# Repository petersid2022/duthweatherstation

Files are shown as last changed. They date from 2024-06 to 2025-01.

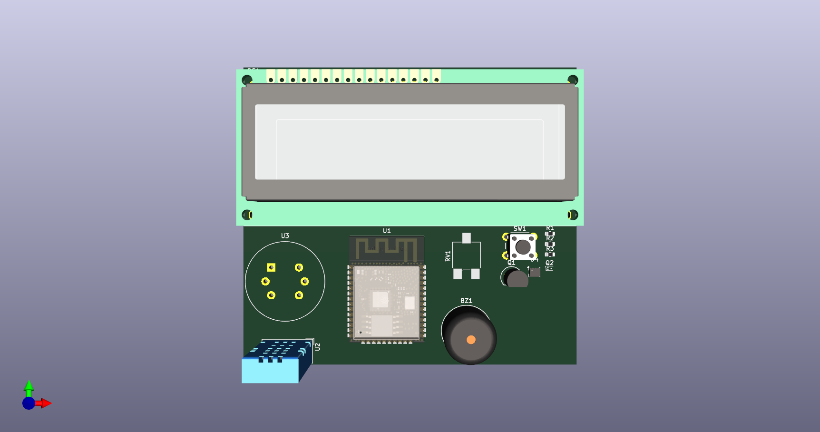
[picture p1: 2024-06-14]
esp32/1.png

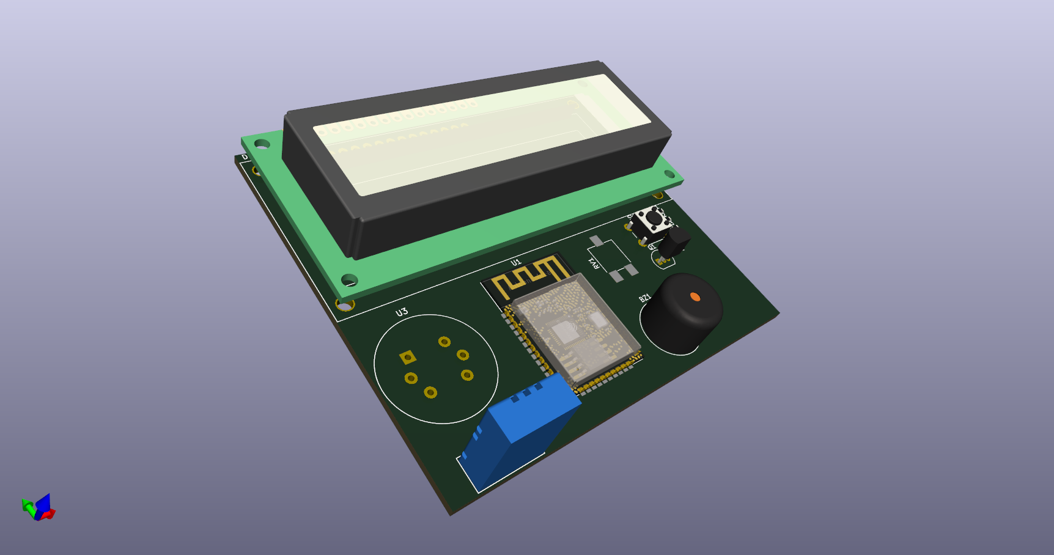
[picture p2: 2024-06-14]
esp32/2.png

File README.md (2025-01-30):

# duthweatherstation

This repo contains a proposed implementation of an Integrated Automatic Weather Station, centered around the FireBeetle 2 ESP32-E microcontroller, that's based on the ESP-WROOM-32E, chosen for its ultra-low power consumption, on-board charging circuit and compatibility with a wide range of sensors. The sensor array includes a DHT11 for humidity, a BMP180 for temperature and barometric pressure, and an MQ135 for air quality monitoring.

Included in this repo:
* The ESP32 firmware
* The Go microservice that handles the data stream from the ESP32 and various SQL transactions with the MySQL database
* Our Go/TEMPL frontend app
* The final board schematic, designed using KiCad
* Various 3D renderings of the PCB generated using KiCad
* The paper that describes in detail our implementation

~~You can view the live production app on: https://duthweatherstation.azurewebsites.net/~~





## License
This project is licensed under the MIT License.

(The MIT License)
Copyright (c) 2024 Peter Sideris petersid2022@gmail.com
Permission is hereby granted, free of charge, to any person obtaining a copy of this software and associated documentation files (the 'Software'), to deal in the Software without restriction, including without limitation the rights to use, copy, modify, merge, publish, distribute, sublicense, and/or sell copies of the Software, and to permit persons to whom the Software is furnished to do so, subject to the following conditions:
The above copyright notice and this permission notice shall be included in all copies or substantial portions of the Software.
THE SOFTWARE IS PROVIDED 'AS IS', WITHOUT WARRANTY OF ANY KIND, EXPRESS OR IMPLIED, INCLUDING BUT NOT LIMITED TO THE WARRANTIES OF MERCHANTABILITY, FITNESS FOR A PARTICULAR PURPOSE AND NONINFRINGEMENT. IN NO EVENT SHALL THE AUTHORS OR COPYRIGHT HOLDERS BE LIABLE FOR ANY CLAIM, DAMAGES OR OTHER LIABILITY, WHETHER IN AN ACTION OF CONTRACT, TORT OR OTHERWISE, ARISING FROM, OUT OF OR IN CONNECTION WITH THE SOFTWARE OR THE USE OR OTHER DEALINGS IN THE SOFTWARE.

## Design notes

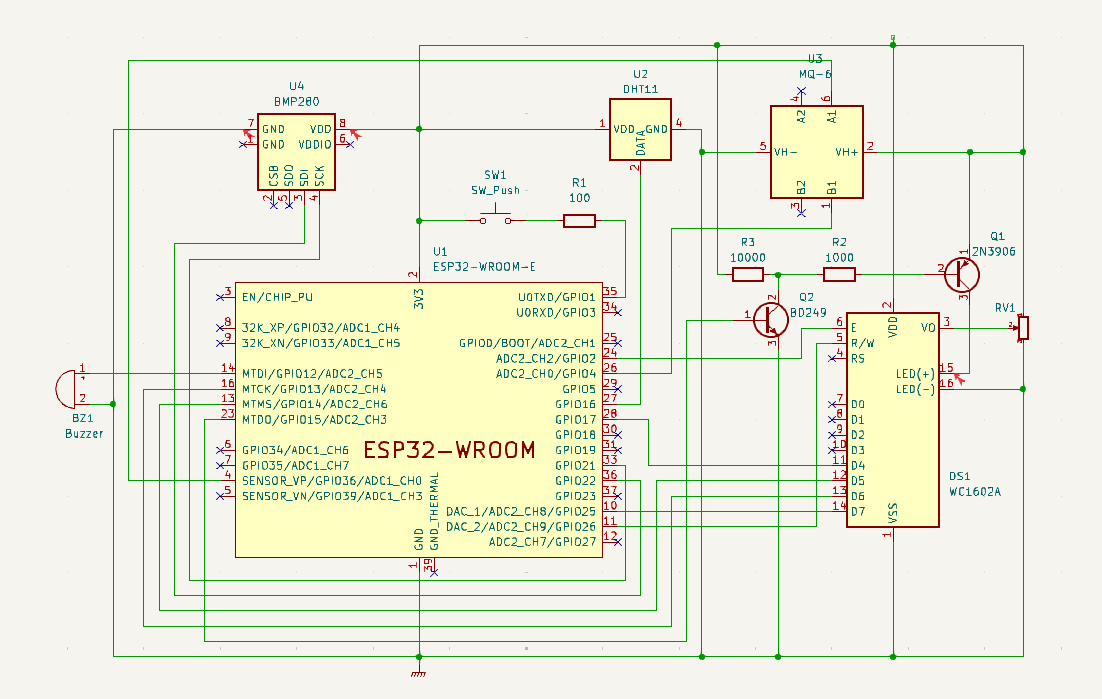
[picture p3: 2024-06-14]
esp32/schematic.png

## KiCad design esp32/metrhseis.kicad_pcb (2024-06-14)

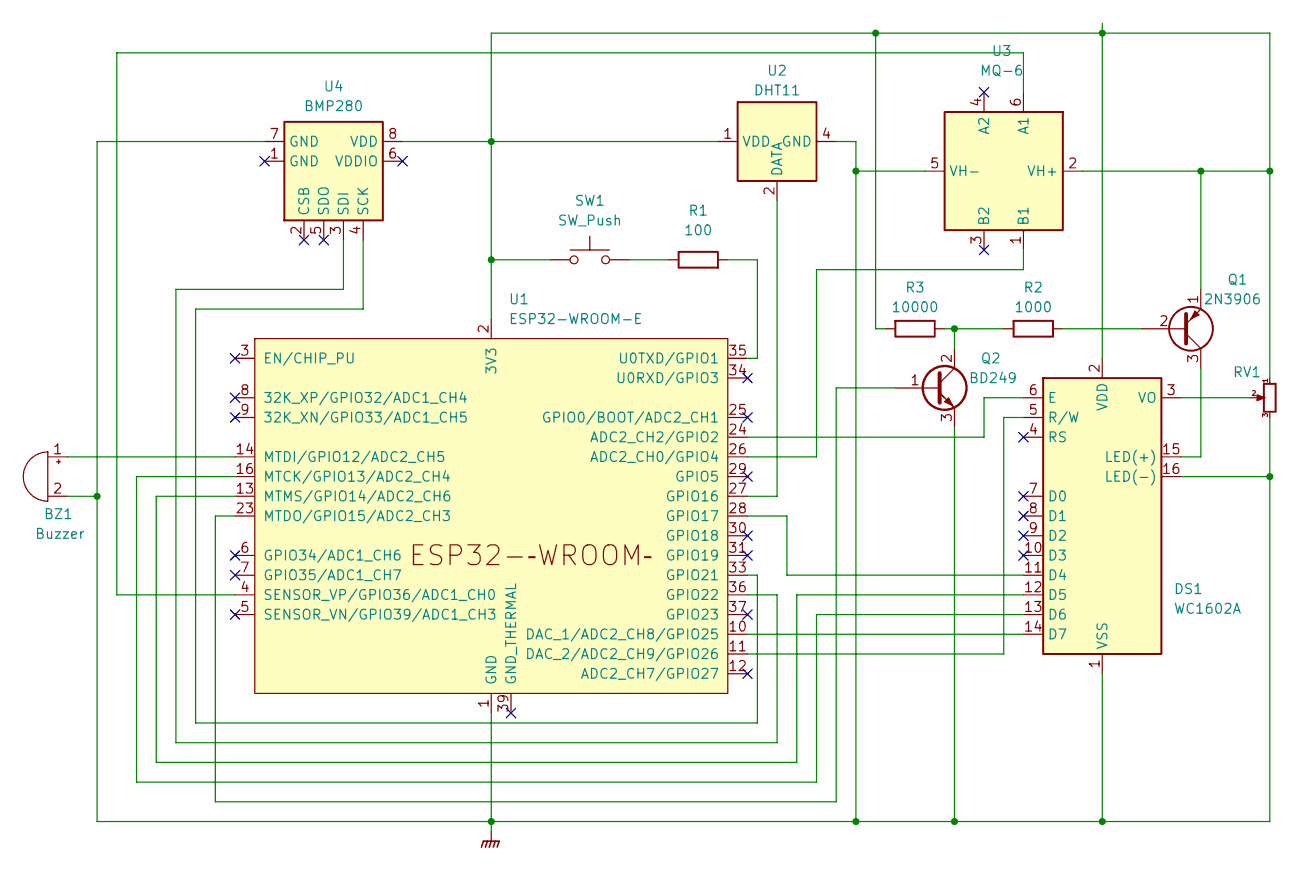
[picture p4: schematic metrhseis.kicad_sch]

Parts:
BZ1: Buzzer; Buzzer_12x9.5RM7.6
DS1: WC1602A
Q1: 2N3906; TO-92_Inline
Q2: BD249; SOT-1123
R1: 100; R_0603_1608Metric
R2: 1000; R_0603_1608Metric
R3: 10000; R_0603_1608Metric
RV1: R_Potentiometer_Small; Potentiometer_ACP_CA6-VSMD_Vertical
SW1: SW_Push; SW_PUSH_6mm
U1: ESP32-WROOM-E; ESP32-WROOM-32E
U2: DHT11; Aosong_DHT11_5.5x12.0_P2.54mm
U3: MQ-6
U4: BMP280; Bosch_LGA-8_2x2.5mm_P0.65mm_ClockwisePinNumbering

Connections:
GNDPWR: BZ1.2 (-), DS1.1 (VSS), DS1.16 (LED(-)), Q2.3 (E), RV1.3, U1.1 (GND), U1.15 (GND), U1.38 (GND), U2.4 (GND), U3.5 (VH-), U4.7 (GND)
unnamed: BZ1.1 (+), U1.14 (MTDI/GPIO12/ADC2_CH5)
unnamed: DS1.11 (D4), U1.28 (GPIO17)
unnamed: DS1.12 (D5), U1.13 (MTMS/GPIO14/ADC2_CH6)
unnamed: DS1.13 (D6), U1.16 (MTCK/GPIO13/ADC2_CH4)
unnamed: DS1.14 (D7), U1.10 (DAC_1/ADC2_CH8/GPIO25)
unnamed: DS1.6 (E), U1.24 (ADC2_CH2/GPIO2)
unnamed: DS1.15 (LED(+)), Q1.3 (C)
unnamed: DS1.5 (R/W), U1.11 (DAC_2/ADC2_CH9/GPIO26)
unnamed: DS1.2 (VDD), Q1.1 (E), R3.2, RV1.1, SW1.1, U1.2 (3V3), U2.1 (VDD), U3.2 (VH+), U4.8 (VDD)
unnamed: DS1.3 (VO), RV1.2
unnamed: Q1.2 (B), R2.1
unnamed: Q2.1 (B), U1.23 (MTDO/GPIO15/ADC2_CH3)
unnamed: Q2.2 (C), R2.2, R3.1
unnamed: R1.1, SW1.2
unnamed: U1.26 (ADC2_CH0/GPIO4), U3.1 (B1)
unnamed: U1.27 (GPIO16), U2.2 (DATA)
unnamed: U1.33 (GPIO21), U4.4 (SCK)
unnamed: U1.36 (GPIO22), U4.3 (SDI)
unnamed: U1.4 (SENSOR_VP/GPIO36/ADC1_CH0), U3.6 (A1)
unnamed: R1.2, U1.35 (U0TXD/GPIO1)

Board: 2 copper layers, 13 parts (0 on the bottom side), 21 nets, no tracks yet.

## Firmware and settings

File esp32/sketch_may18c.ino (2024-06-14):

#include <WiFi.h>
#include "DHT.h"
#include "time.h"
#include <LiquidCrystal.h>
#include <Wire.h>
#include <Adafruit_BMP085.h>
#include <HTTPClient.h>
#include <WiFiClientSecure.h>
#include <Ticker.h>

#define DHTPIN D11
#define DHTTYPE DHT11
#define GAS_DIN D12
#define GAS_AIN A0
#define BUZZER_PIN D13
#define LCD_BACKLIGHT A4
#define PUSH_BUTTON_PIN 1

int ad_value, gas;
float h, t, p;
const char *ssid = "esp32-wifi";
const char *password = "123456789";
const char *serverName = "https://duthweather.azurewebsites.net/api/add";
const char *ntpServer = "pool.ntp.org";
const long gmtOffset_sec = 7200;
const int daylightOffset_sec = 3600;
unsigned long lastDataSentTime = 0;
const unsigned long sendDataInterval = 2 * 60 * 1000;
volatile bool backlightState = false;

Ticker gasSensorTicker;
Ticker buttonCheckTicker;
LiquidCrystal lcd(26, 2, 17, 14, 13, 25);  // ( RS, EN, D4, D5, D6, D7 )
DHT dht(DHTPIN, DHTTYPE);
Adafruit_BMP085 bmp;

void IRAM_ATTR handleButtonPress() {
  backlightState = !backlightState;
  digitalWrite(LCD_BACKLIGHT, backlightState ? HIGH : LOW);
}

void gasSensorCheck() {
  ad_value = analogRead(GAS_AIN);
  if (ad_value >= 2500) {
    while (ad_value >= 2500) {
      lcd.clear();
      delay(50);
      lcd.setCursor(0, 0);
      lcd.print("DANGER! Gas");
      lcd.setCursor(0, 1);
      lcd.print("leakage detected");
      digitalWrite(BUZZER_PIN, HIGH);
      delay(100);
      digitalWrite(BUZZER_PIN, LOW);
      delay(100);
      ad_value = analogRead(GAS_AIN);
      delay(50);
    }
  }
}

void checkButton() {
  static bool lastButtonState = HIGH;
  bool currentButtonState = digitalRead(PUSH_BUTTON_PIN);
  if (lastButtonState == HIGH && currentButtonState == LOW) {
    handleButtonPress();
  }
  lastButtonState = currentButtonState;
}

const char *rootCACertificate =
  "-----BEGIN CERTIFICATE-----\n"
  "MIIDjjCCAnagAwIBAgIQAzrx5qcRqaC7KGSxHQn65TANBgkqhkiG9w0BAQsFADBh\n"
  "MQswCQYDVQQGEwJVUzEVMBMGA1UEChMMRGlnaUNlcnQgSW5jMRkwFwYDVQQLExB3\n"
  "d3cuZGlnaWNlcnQuY29tMSAwHgYDVQQDExdEaWdpQ2VydCBHbG9iYWwgUm9vdCBH\n"
  "MjAeFw0xMzA4MDExMjAwMDBaFw0zODAxMTUxMjAwMDBaMGExCzAJBgNVBAYTAlVT\n"
  "MRUwEwYDVQQKEwxEaWdpQ2VydCBJbmMxGTAXBgNVBAsTEHd3dy5kaWdpY2VydC5j\n"
  "b20xIDAeBgNVBAMTF0RpZ2lDZXJ0IEdsb2JhbCBSb290IEcyMIIBIjANBgkqhkiG\n"
  "9w0BAQEFAAOCAQ8AMIIBCgKCAQEAuzfNNNx7a8myaJCtSnX/RrohCgiN9RlUyfuI\n"
  "2/Ou8jqJkTx65qsGGmvPrC3oXgkkRLpimn7Wo6h+4FR1IAWsULecYxpsMNzaHxmx\n"
  "1x7e/dfgy5SDN67sH0NO3Xss0r0upS/kqbitOtSZpLYl6ZtrAGCSYP9PIUkY92eQ\n"
  "q2EGnI/yuum06ZIya7XzV+hdG82MHauVBJVJ8zUtluNJbd134/tJS7SsVQepj5Wz\n"
  "tCO7TG1F8PapspUwtP1MVYwnSlcUfIKdzXOS0xZKBgyMUNGPHgm+F6HmIcr9g+UQ\n"
  "vIOlCsRnKPZzFBQ9RnbDhxSJITRNrw9FDKZJobq7nMWxM4MphQIDAQABo0IwQDAP\n"
  "BgNVHRMBAf8EBTADAQH/MA4GA1UdDwEB/wQEAwIBhjAdBgNVHQ4EFgQUTiJUIBiV\n"
  "5uNu5g/6+rkS7QYXjzkwDQYJKoZIhvcNAQELBQADggEBAGBnKJRvDkhj6zHd6mcY\n"
  "1Yl9PMWLSn/pvtsrF9+wX3N3KjITOYFnQoQj8kVnNeyIv/iPsGEMNKSuIEyExtv4\n"
  "NeF22d+mQrvHRAiGfzZ0JFrabA0UWTW98kndth/Jsw1HKj2ZL7tcu7XUIOGZX1NG\n"
  "Fdtom/DzMNU+MeKNhJ7jitralj41E6Vf8PlwUHBHQRFXGU7Aj64GxJUTFy8bJZ91\n"
  "8rGOmaFvE7FBcf6IKshPECBV1/MUReXgRPTqh5Uykw7+U0b6LJ3/iyK5S9kJRaTe\n"
  "pLiaWN0bfVKfjllDiIGknibVb63dDcY3fe0Dkhvld1927jyNxF1WW6LZZm6zNTfl\n"
  "MrY=\n"
  "-----END CERTIFICATE-----\n";

String printLocalTime() {
  struct tm timeinfo;
  if (!getLocalTime(&timeinfo)) {
    return "";
  }
  time_t timestamp = mktime(&timeinfo);
  char formattedTime[30];
  strftime(formattedTime, sizeof(formattedTime), "%Y-%m-%dT%H:%M:%SZ", &timeinfo);
  return String(formattedTime);
}

void setup() {
  lcd.begin(16, 2);
  dht.begin();
  if (!bmp.begin()) {
    while (1) {}
  }

  pinMode(GAS_DIN, INPUT);
  pinMode(GAS_AIN, INPUT);
  pinMode(PUSH_BUTTON_PIN, INPUT);
  pinMode(BUZZER_PIN, OUTPUT);
  pinMode(LCD_BACKLIGHT, OUTPUT);
  digitalWrite(LCD_BACKLIGHT, HIGH);

  lcd.clear();
  lcd.setCursor(0, 0);
  lcd.print("Connecting to");
  lcd.setCursor(0, 1);
  lcd.print("wifi");
  WiFi.begin(ssid, password);

  unsigned long startAttemptTime = millis();
  while (WiFi.status() != WL_CONNECTED && millis() - startAttemptTime < 10000) {
    for (int i = 0; i < 3; i++) {
      delay(500);
      lcd.print(".");
    }
    delay(500);
    lcd.setCursor(0, 1);
    lcd.print("wifi   ");
    delay(500);
    lcd.setCursor(0, 1);
    lcd.print("wifi");
  }

  if (WiFi.status() == WL_CONNECTED) {
    lcd.clear();
    lcd.setCursor(0, 0);
    lcd.print("Connected to:");
    lcd.setCursor(0, 1);
    lcd.print(ssid);

    configTime(gmtOffset_sec, daylightOffset_sec, ntpServer);
    printLocalTime();
  } else {
    lcd.clear();
    lcd.home();
    lcd.print("Couldn't connect");
    lcd.setCursor(0, 1);
    lcd.print("to wifi");
    delay(2500);
    lcd.clear();
  }

  buttonCheckTicker.attach(0.05, checkButton);
  gasSensorTicker.attach(0.5, gasSensorCheck);
}

void DisplaySensorData(int ad_value, float h, float t, float p) {
  lcd.clear();
  lcd.setCursor(0, 0);
  lcd.print("Humidity: ");
  lcd.setCursor(0, 1);
  lcd.print(h);
  lcd.print(" %");
  delay(2500);

  lcd.clear();
  lcd.setCursor(0, 0);
  lcd.print("Temperature: ");
  lcd.setCursor(0, 1);
  lcd.print(t);
  lcd.print(" C");
  delay(2500);

  lcd.clear();
  lcd.setCursor(0, 0);
  lcd.print("Gas sensor: ");
  lcd.setCursor(0, 1);
  lcd.print(ad_value);
  lcd.print(" ppm");
  delay(2500);

  lcd.clear();
  lcd.setCursor(0, 0);
  lcd.print("Pressure: ");
  lcd.setCursor(0, 1);
  lcd.print(p);
  lcd.print(" hPa");
  delay(2500);
}

String createPayload(const String &sensorName, const String &timestamp, const String &data) {
  return "{\"SensorName\":\"" + sensorName + "\",\"SensorData\":{\"timestamp\":\"" + timestamp + "\"," + data + "}}";
}

void sendData(int ad_value, float h, float t, float p) {
  const int maxRetries = 3;
  int attempts = 0;
  bool success = false;

  while (attempts < maxRetries && !success) {
    WiFiClientSecure *client = new WiFiClientSecure;
    if (client) {
      lcd.clear();
      lcd.setCursor(0, 0);
      lcd.print("Uploading data");
      delay(500);

      client->setCACert(rootCACertificate);

      HTTPClient https;
      if (https.begin(*client, serverName)) {
        String timestamp = printLocalTime();
        int httpResponseCode;

        String payload_dht11 = createPayload("dht11", timestamp, "\"humidity\":" + String(h));
        httpResponseCode = https.POST(payload_dht11);

        if (httpResponseCode > 0) {
          String payload_bmp180 = createPayload("bmp180", timestamp, "\"temperature\":" + String(t) + ",\"pressure\":" + String(p));
          httpResponseCode = https.POST(payload_bmp180);

          if (httpResponseCode > 0) {
            String payload_mq135 = createPayload("mq135", timestamp, "\"gas_level\":" + String(ad_value));
            httpResponseCode = https.POST(payload_mq135);
          }
        }

        https.end();

        if (httpResponseCode > 0) {
          success = true;
          lcd.setCursor(0, 1);
          lcd.print("Done!");
          delay(2000);
          lcd.clear();
        } else {
          attempts++;
          lcd.setCursor(0, 1);
          lcd.print("Retrying...");
          delay(2500);
          lcd.clear();
        }
      } else {
        lcd.setCursor(0, 1);
        lcd.print("Connection failed");
        delay(2500);
        lcd.clear();
        attempts++;
      }
    }
    delete client;
  }

  if (!success) {
    lcd.setCursor(0, 1);
    lcd.print("Failed after retries");
    delay(2000);
    lcd.clear();
  }
}

void loop() {
  unsigned long currentTime = millis();

  if (currentTime - lastDataSentTime >= sendDataInterval) {
    lastDataSentTime = currentTime;
    // ad_value = analogRead(GAS_AIN);
    gas = analogRead(GAS_AIN);
    ad_value = gas - 120;
    ad_value = map(ad_value, 0, 1024, 400, 5000);
    h = dht.readHumidity();
    t = bmp.readTemperature();
    p = bmp.readPressure() / 100.0;
    if (WiFi.status() == WL_CONNECTED) {
      sendData(ad_value, h, t, p);
    }
  } else {
    // ad_value = analogRead(GAS_AIN);
    gas = analogRead(GAS_AIN);
    ad_value = gas - 120;
    ad_value = map(ad_value, 0, 1024, 400, 5000);
    h = dht.readHumidity();
    t = bmp.readTemperature();
    p = bmp.readPressure() / 100.0;
    DisplaySensorData(ad_value, h, t, p);
  }
}

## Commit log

2024-05-26 Added esp32 sketch code
2024-05-26 esp32: disable screen after sending data for 5 minutes
2024-05-27 Updated ESP32 code
2024-05-27 Display last sensor readings
2024-05-29 duthweatherstation v1.4 auto scale y axis and make charts prettier
2024-05-30 esp32: enable immediate LCD backlight control with button press
2024-06-14 Updated esp32 sketch
2024-06-14 Added kicad project files
    [metrhseis.kicad_pcb, metrhseis.kicad_sch]
